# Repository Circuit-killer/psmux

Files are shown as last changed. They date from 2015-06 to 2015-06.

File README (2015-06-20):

12V DC power supply multiplexer.

It was primarly designed to get a 2 level redundancy power
supply. 2 input sources - a 12V AC/DC wall adapter and a
regulated solar panel - are multiplexed using an application
specific logic implemented on a microcontroller. In the case
of a redundant power supply, the logic switches from one
source to another in case of low voltage detection.

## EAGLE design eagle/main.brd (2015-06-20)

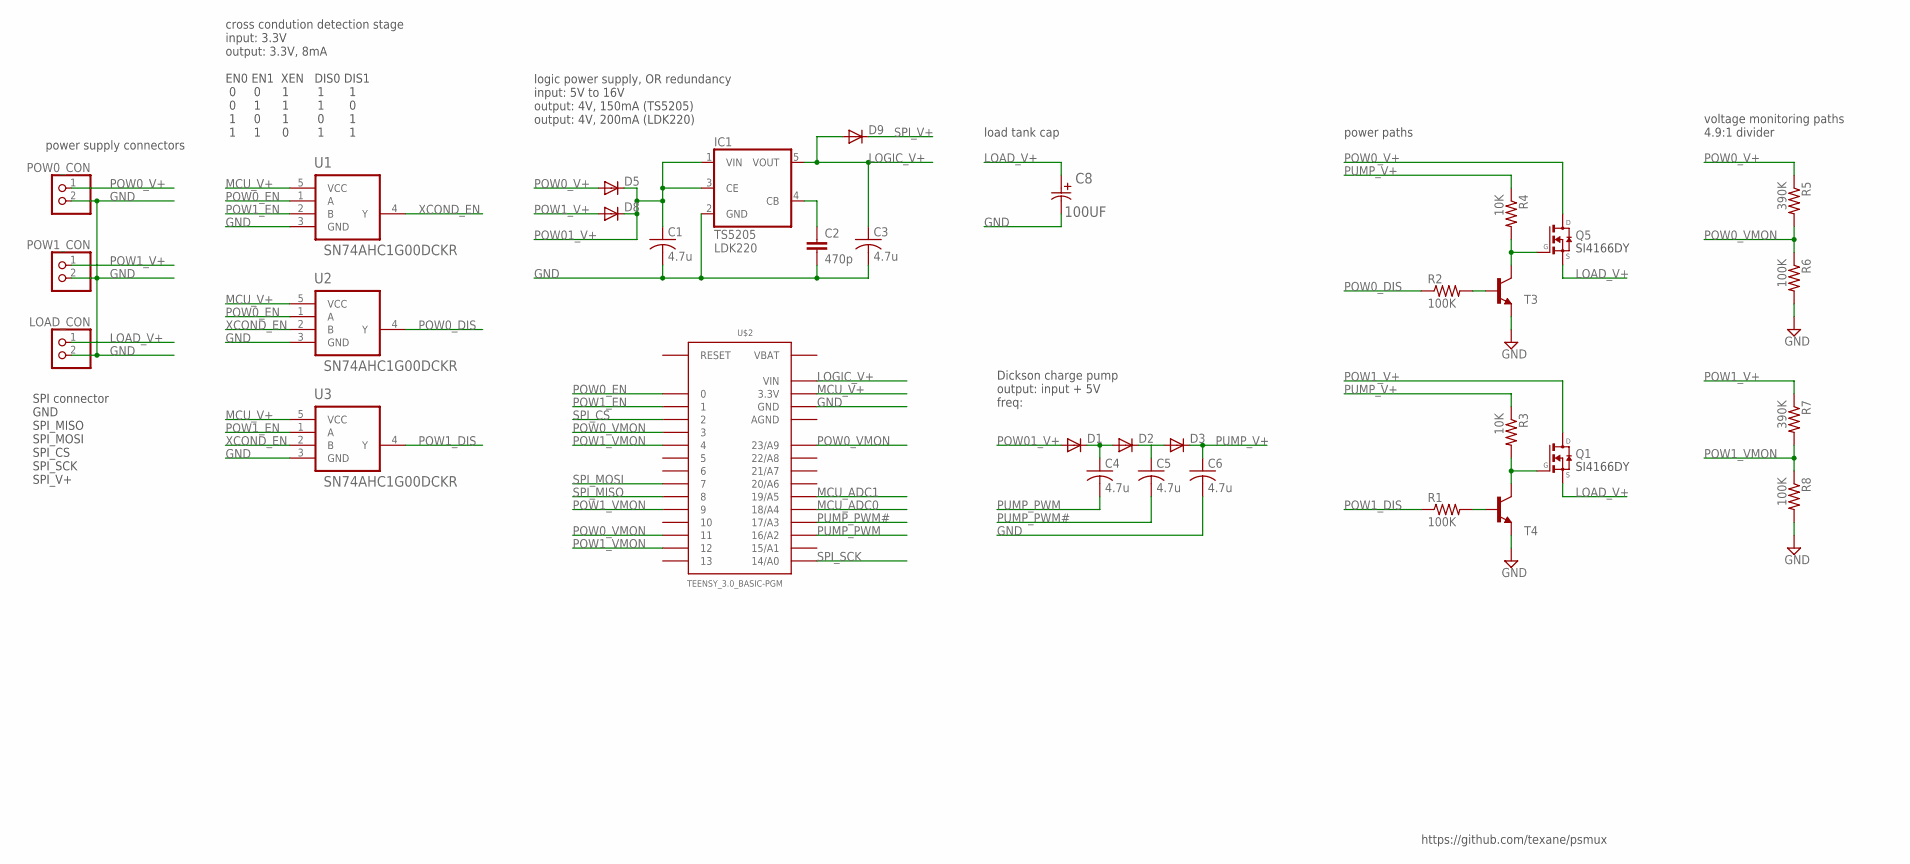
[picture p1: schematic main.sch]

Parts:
C1, C3, C4, C5, C6: 4.7u; C1210K
C2: 470p; C0805K
C8: 100UF; CAPAE660X800N
D1, D2, D3, D5, D8, D9: DIODE-DO214AC; DO214AC
IC1: TS5205; SOT25
LOAD_CON: PINHD-1X2; 1X02
POW0_CON, POW1_CON: PINHD-1X2; 1X02
Q1, Q5: SI4840DY; SO08-E3
R1, R2, R6, R8: 100K; M0805
R3, R4: 10K; M0805
R5, R7: 390K; M0805
T3, T4: BC817-40-NPN-SOT23-BEC; SOT23-BEC
U1, U2, U3: SN74AHC1G00DCKR; SOT65P210X110-5N
U$2: TEENSY_3.0_BASIC-PGM

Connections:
AGND: U$2.AGND
GND: C1.2, C2.2, C3.2, C6.2, C8.2, IC1.2 (GND), LOAD_CON.2, POW0_CON.2, POW1_CON.2, R6.2, R8.2, T3.E, T4.E, U1.3 (GND), U2.3 (GND), U3.3 (GND), U$2.GND, U$2.GND1 (GND)
LOAD_V+: C8.1, LOAD_CON.1, Q1.1-3 (S), Q5.1-3 (S)
LOGIC_V+: C3.1, D9.A, IC1.5 (VOUT), U$2.VIN
MCU_ADC0: U$2.18/A4
MCU_ADC1: U$2.19/A5
MCU_V+: U1.5 (VCC), U2.5 (VCC), U3.5 (VCC), U$2.3.3V, U$2.3.3V1 (3.3V)
unnamed: Q5.4 (G), R4.2, T3.C
unnamed: Q1.4 (G), R3.2, T4.C
unnamed: R1.2, T4.B
unnamed: C4.1, D1.C, D2.A
unnamed: C5.1, D2.C, D3.A
unnamed: R2.2, T3.B
unnamed: C2.1, IC1.4 (CB)
POW0_DIS: R2.1, U2.4 (Y)
POW0_EN: U1.1 (A), U2.1 (A), U$2.0
POW0_V+: D5.A, POW0_CON.1, Q5.5-8 (D), R5.1
POW0_VMON: R5.2, R6.1, U$2.3, U$2.11, U$2.23/A9
POW1_DIS: R1.1, U3.4 (Y)
POW1_EN: U1.2 (B), U3.1 (A), U$2.1
POW01_V+: C1.1, D1.A, D5.C, D8.C, IC1.1 (VIN), IC1.3 (CE)
POW1_V+: D8.A, POW1_CON.1, Q1.5-8 (D), R7.1
POW1_VMON: R7.2, R8.1, U$2.4, U$2.9, U$2.12
PUMP_PWM: C4.2, U$2.16/A2
PUMP_PWM#: C5.2, U$2.17/A3
PUMP_V+: C6.1, D3.C, R3.1, R4.1
SPI_CS: U$2.2
SPI_MISO: U$2.8
SPI_MOSI: U$2.7
SPI_SCK: U$2.14/A0
SPI_V+: D9.C
VBAT: U$2.VBAT
XCOND_EN: U1.4 (Y), U2.2 (B), U3.2 (B)

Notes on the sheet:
cross condution detection stage input: 3.3V output: 3.3V, 8mA EN0 EN1 XEN DIS0 DIS1 0 0 1 1 1 0 1 1 1 0 1 0 1 0 1 1 1 0 1 1
power supply connectors
logic power supply, OR redundancy input: 5V to 16V output: 4V, 150mA (TS5205) output: 4V, 200mA (LDK220)
load tank cap
Dickson charge pump output: input + 5V freq:
power paths
voltage monitoring paths 4.9:1 divider
SPI connector GND SPI_MISO SPI_MOSI SPI_CS SPI_SCK SPI_V+
SI4166DY
TS5205 LDK220
https://github.com/texane/psmux

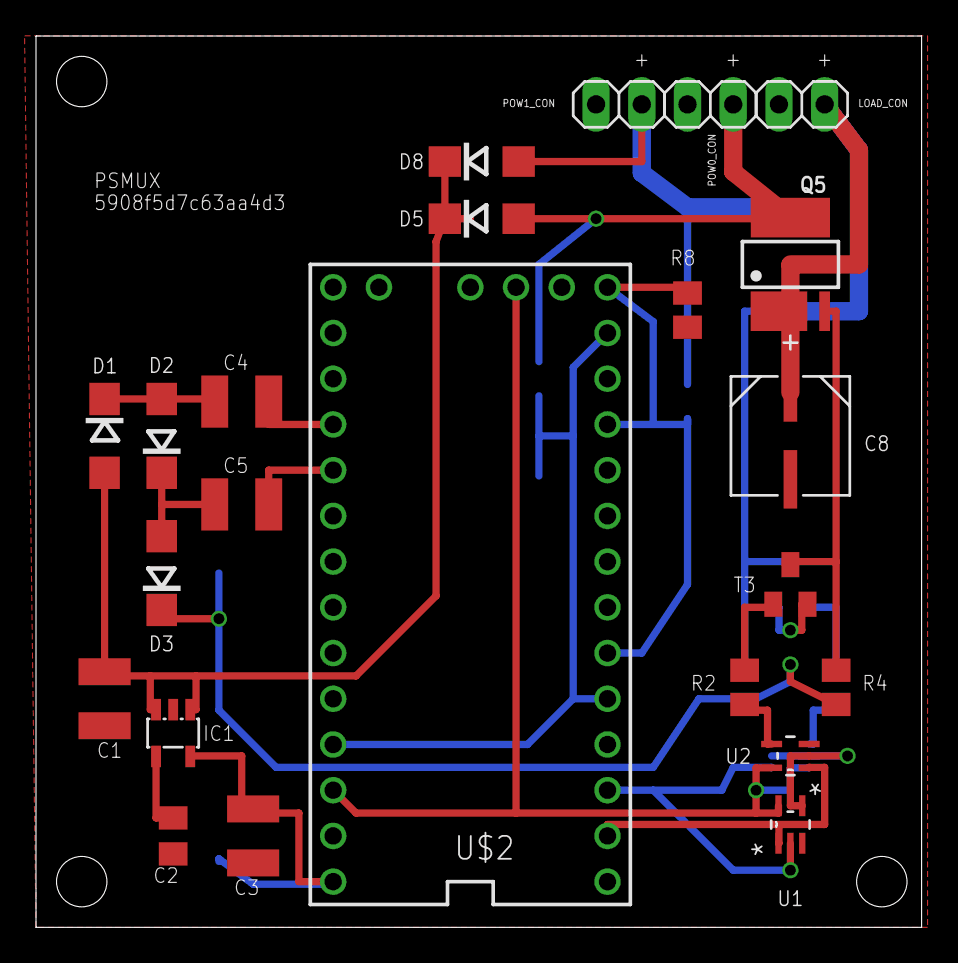
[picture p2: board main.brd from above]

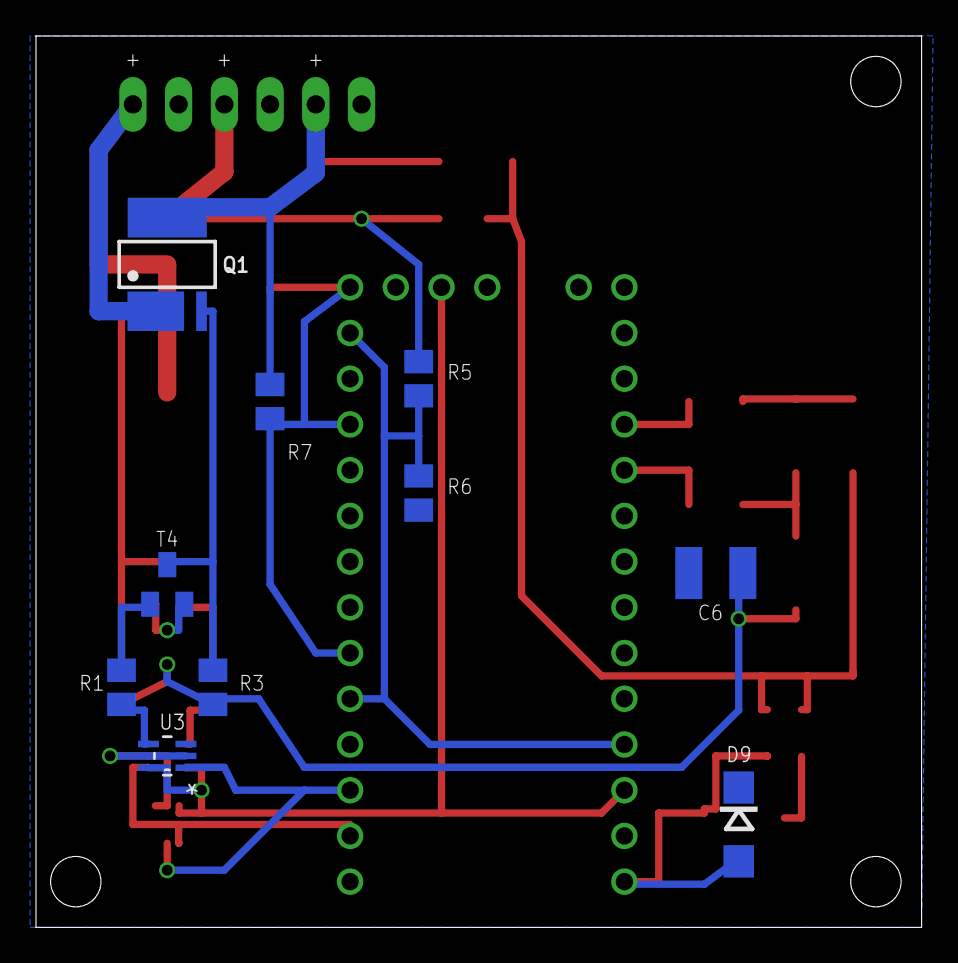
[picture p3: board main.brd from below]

Board: 2 copper layers, 49.2 x 49.5 mm, 33 parts (10 on the bottom side), 24 nets.

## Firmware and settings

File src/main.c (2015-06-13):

#include <stdint.h>
#include "mk20dx128.h"
#include "serial.c"
#include "led.c"


extern void delay(uint32_t);


/* pwm */

/* FTM1 clock (ie. F_CPU) prescaler. must be at least 2 */
#define FTM1_DIV (2)

static inline uint16_t pwm_freq_to_counter(uint32_t freq)
{
  /* freq max: 12MHz */
  /* freq resoultion: 366Hz */

  /* 1 / freq = counter / (f_cpu / f_div); */
  /* counter = f_cpu / (f_div * freq) */

  return (uint16_t)(F_CPU / (FTM1_DIV * freq));
}

static void pwm_start(void)
{
  /* setup ftm1 so that channel A is set as a pwm */
  /* with 50% duty and channel B is its complement. */
  /* for this to work, linked channels are used and */
  /* the hardware assumes B = A + 1 */

  /* pinout */
  /* pwm:  teensy_16, 35, PORTB0_ALT3, FTM1_CH0 */
  /* pwm#: teensy_17, 36, PORTB1_ALT3, FTM1_CH1 */

  /* ftm1 channel indices */
#define PWM_CHA (0)
#define PWM_CHB (PWM_CHA + 1)

#if (PWM_CHA != 0)
#error "TODO"
#endif /* (PWM_CHA != 0) */

  /* enable ftm1 clock */
  /* note, p.823: FTM1_FREQ can not exceed F_CPU / 2 */
  SIM_SCGC6 |= 1 << 25;

  /* disable counter clocking */
  /* important, otherwise counters do not get load */
  FTM1_SC = 0;

  /* configure pin mux */
  PORTB_PCR0 = 3 << 8;
  PORTB_PCR1 = 3 << 8;

  /* disable write protection */
  FTM1_MODE = 1 << 2;

  /* set pwm 16 bits counter and modulos */
  /* duty is set to 50%, ie. frequency / 2 */
  /* complementary channel inverted from n/2 to n */
#define PWM_FREQ 50000
  const uint16_t n = pwm_freq_to_counter(PWM_FREQ);
  FTM1_MOD = n;
  FTM1_C0V = n / 2;
  FTM1_C1V = n;

  /* load counter initial value */
  /* note p.835: only use FTM1_CNTIN = 0 */
  FTM1_CNTIN = 0;

  /* ftm1 channel setup */
  /* edge aligned pwm, clear output on match */
  FTM1_C0SC = (2 << 4) | (2 << 2);
  FTM1_C1SC = (2 << 4) | (2 << 2);

  /* output initial state */
  FTM1_OUTINIT = 1 << PWM_CHB;

  /* per channel response on match mask */
  FTM1_OUTMASK = 0;

  /* linked channels configuration */
  /* enable complementarity */
  FTM1_COMBINE = (1 << 1) | (1 << 0);

  /* set channel polarity as active high */
  FTM1_POL = 0;

  /* disable fault inputs */
  FTM1_FLTCTRL = 0;

  /* disable quadrature encoder */
  FTM1_QDCTRL = 0;

  /* synchronization configuration */
  FTM1_SYNCONF = (1 << 7) | (1 << 2);

  /* channel inversion configuration */
  FTM1_INVCTRL = 0;

  /* disable software output control */
  FTM1_SWOCTRL = 0;

  /* pwm counter loading */
  FTM1_PWMLOAD = 0;

  /* configure mode */
  /* disable write protection */
  /* initialize channel outputs */
  /* enable all registers */
  FTM1_MODE = (1 << 2) | (1 << 1) | (1 << 0);

  /* enable counter using system clock */
  /* note, p.823: FTM1_FREQ can not exceed F_CPU / 2 */
#if (FTM1_DIV == 2)
  FTM1_SC = (1 << 3) | (1 << 0);
#else
#error "TODO"
#endif
}

static void pwm_stop(void)
{
  /* disable write protection */
  FTM1_MODE = 1 << 2;

  /* disable counter clocking */
  FTM1_SC = 0 << 3;
}

__attribute__((unused))
static void pwm_set_high(void)
{
  /* set CHA high */
  FTM1_SWOCTRL = (1 << 8) | (1 << 0);
}


__attribute__((unused))
static void pwm_set_low(void)
{
  /* set CHA low */
  FTM1_SWOCTRL = (0 << 8) | (1 << 0);
}


/* main */

int main(void)
{
  led_setup();

  pwm_start();

  while (1)
  {
    led_set_val(1);
    delay(250);

    led_set_val(0);
    delay(250);
  }

  pwm_stop();

  return 0;
}

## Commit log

2015-06-08 add doc eagle spice
    [main.sch]
2015-06-08 update schematic
    [main.sch]
2015-06-08 add teensy eagle library
2015-06-08 add main.bom
2015-06-08 update schematics
    [main.sch]
2015-06-12 add board
    [main.brd]
2015-06-12 schottky diodes
    [main.brd, main.sch]
2015-06-12 update board
    [main.brd, main.sch]
2015-06-13 set PWM_FREQ to 50KHz
2015-06-13 add 2.2UF and ceramic caps
    [main.sch]
2015-06-13 update routing
    [main.brd]
2015-06-20 power terminals
    [main.brd]
2015-06-20 remove schematics TODO
    [main.brd, main.sch]
